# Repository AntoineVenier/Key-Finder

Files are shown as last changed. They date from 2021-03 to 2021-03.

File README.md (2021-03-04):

# Key Tracker

The goal of this project is to design a small embedded device that you can attach to your key in order to find them when they are lost.

## How it work

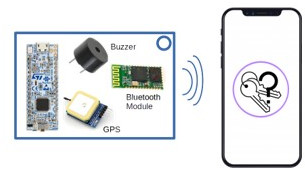
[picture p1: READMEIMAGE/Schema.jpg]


On the board which is attach to your key you have nucleo board which communicate with a GPS and Send the Location of the key to a mobile application thanks to a Bluetooth Module.
You can also detect the location of the key by making sound the buzzer.

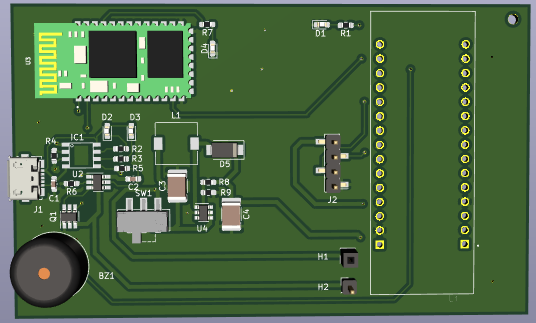
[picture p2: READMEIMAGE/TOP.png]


                                    TOP

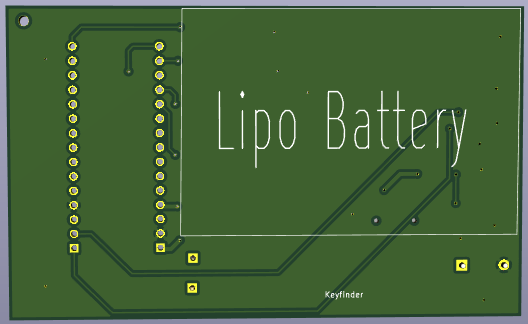
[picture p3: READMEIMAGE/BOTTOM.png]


                                     BOTTOM

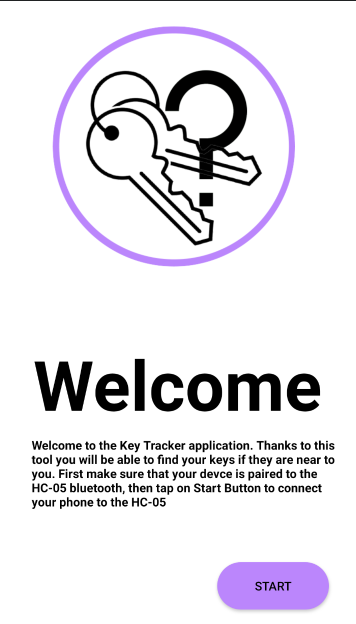
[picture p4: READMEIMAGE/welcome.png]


            Application Welcome page

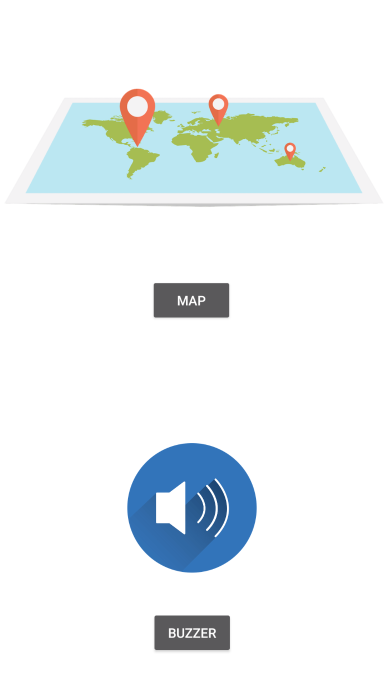
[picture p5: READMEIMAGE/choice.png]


            Application choice page

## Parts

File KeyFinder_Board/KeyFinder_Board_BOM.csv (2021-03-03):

Comment | Designator | Footprint | LCSC Part Numbers
10µF | C1 | Capacitor_SMD:C_0603_1608Metric_Pad1.08x0.95mm_HandSolder | C19702
0.1µF | C2 | Capacitor_SMD:C_0603_1608Metric_Pad1.08x0.95mm_HandSolder | C14663
22µF | C3,C4 | Capacitor_SMD:C_1812_4532Metric_Pad1.57x3.40mm_HandSolder | C59461
LED-RED | D2 | LED_SMD:LED_0603_1608Metric_Pad1.05x0.95mm_HandSolder | C2286
LED-GREEN | D1,D3 | LED_SMD:LED_0603_1608Metric_Pad1.05x0.95mm_HandSolder | C72043
LED-BLUE | D4 | LED_SMD:LED_0603_1608Metric_Pad1.05x0.95mm_HandSolder | C72041
SS34 | D5 | Diode_SMD:D_SMA | C8678
TP4056 | IC1 | mes_empreintes:SOP-8 | C16581
USB_B_Micro | J1 | Connector_USB:USB_Micro-B_Molex_47346-0001 | C404969
22µH | L1 | Inductor_SMD:L_7.3x7.3_H4.5 | C237916
FS8205 | Q1 | mes_empreintes:FS312F-G_SOT-23-6 | C32254
120 | R1 | Resistor_SMD:R_0603_1608Metric_Pad0.98x0.95mm_HandSolder | C22787
1K | R2,R3,R9 | Resistor_SMD:R_0603_1608Metric_Pad0.98x0.95mm_HandSolder | C21190
2K | R4,R6 | Resistor_SMD:R_0603_1608Metric_Pad0.98x0.95mm_HandSolder | C22975
100 | R5 | Resistor_SMD:R_0603_1608Metric_Pad0.98x0.95mm_HandSolder | C22775
47 | R7 | Resistor_SMD:R_0603_1608Metric_Pad0.98x0.95mm_HandSolder | C23182
7,5K | R8 | Resistor_SMD:R_0603_1608Metric_Pad0.98x0.95mm_HandSolder | C23234
SW_SPDT | SW1 | Button_Switch_SMD:SW_SPDT_CK-JS102011SAQN | C405951
FS312F-G | U2 | mes_empreintes:FS312F-G_SOT-23-6 | C82736
MT3608 | U4 | Package_TO_SOT_SMD:SOT-23-6 | C84817

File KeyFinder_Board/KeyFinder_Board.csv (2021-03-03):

Comment | Designator | Footprint | LCSC Part Number
Buzzer | BZ1 | Buzzer_Beeper:Buzzer_12x9.5RM7.6
10µF | C1 | Capacitor_SMD:C_0603_1608Metric_Pad1.08x0.95mm_HandSolder | C19702
0.1µF | C2 | Capacitor_SMD:C_0603_1608Metric_Pad1.08x0.95mm_HandSolder | C14663
22µF | C3,C4 | Capacitor_SMD:C_1812_4532Metric_Pad1.57x3.40mm_HandSolder | C59461
LED-RED | D2 | LED_SMD:LED_0603_1608Metric_Pad1.05x0.95mm_HandSolder | C2286
LED-GREEN | D1,D3 | LED_SMD:LED_0603_1608Metric_Pad1.05x0.95mm_HandSolder | C72043
LED-BLUE | D4 | LED_SMD:LED_0603_1608Metric_Pad1.05x0.95mm_HandSolder | C72041
SS34 | D5 | Diode_SMD:D_SMA | C8678
BAT+ | H1 | Connector_PinSocket_2.54mm:PinSocket_1x01_P2.54mm_Vertical
BAT- | H2 | Connector_PinHeader_2.54mm:PinHeader_1x01_P2.54mm_Vertical
TP4056 | IC1 | mes_empreintes:SOP-8 | C16581
USB_B_Micro | J1 | Connector_USB:USB_Micro-B_Molex_47346-0001 | C404969
GPS-NEO | J2 | Connector_PinHeader_2.54mm:PinHeader_1x04_P2.54mm_Vertical_SMD_Pin1Left
22µH | L1 | Inductor_SMD:L_7.3x7.3_H4.5 | C207843
FS8205 | Q1 | Package_TO_SOT_SMD:SOT-23-6_Handsoldering | C32254
120 | R1 | Resistor_SMD:R_0603_1608Metric_Pad0.98x0.95mm_HandSolder | C22787
1K | R2,R3,R9 | Resistor_SMD:R_0603_1608Metric_Pad0.98x0.95mm_HandSolder | C21190
2K | R4,R6 | Resistor_SMD:R_0603_1608Metric_Pad0.98x0.95mm_HandSolder | C22975
100 | R5 | Resistor_SMD:R_0603_1608Metric_Pad0.98x0.95mm_HandSolder | C22775
47 | R7 | Resistor_SMD:R_0603_1608Metric_Pad0.98x0.95mm_HandSolder | C23182
7,5K | R8 | Resistor_SMD:R_0603_1608Metric_Pad0.98x0.95mm_HandSolder | C23234
SW_SPDT | SW1 | Button_Switch_SMD:SW_SPDT_CK-JS102011SAQN | C405951
NucleoBoard | U1 | mes_empreintes:MODULE_NUCLEO-L432KC
FS312F-G | U2 | Package_TO_SOT_SMD:SOT-23-6_Handsoldering | C82736
HC-05 | U3 | HC-05(1):XCVR_HC-05
MT3608 | U4 | Package_TO_SOT_SMD:SOT-23-6 | C84817

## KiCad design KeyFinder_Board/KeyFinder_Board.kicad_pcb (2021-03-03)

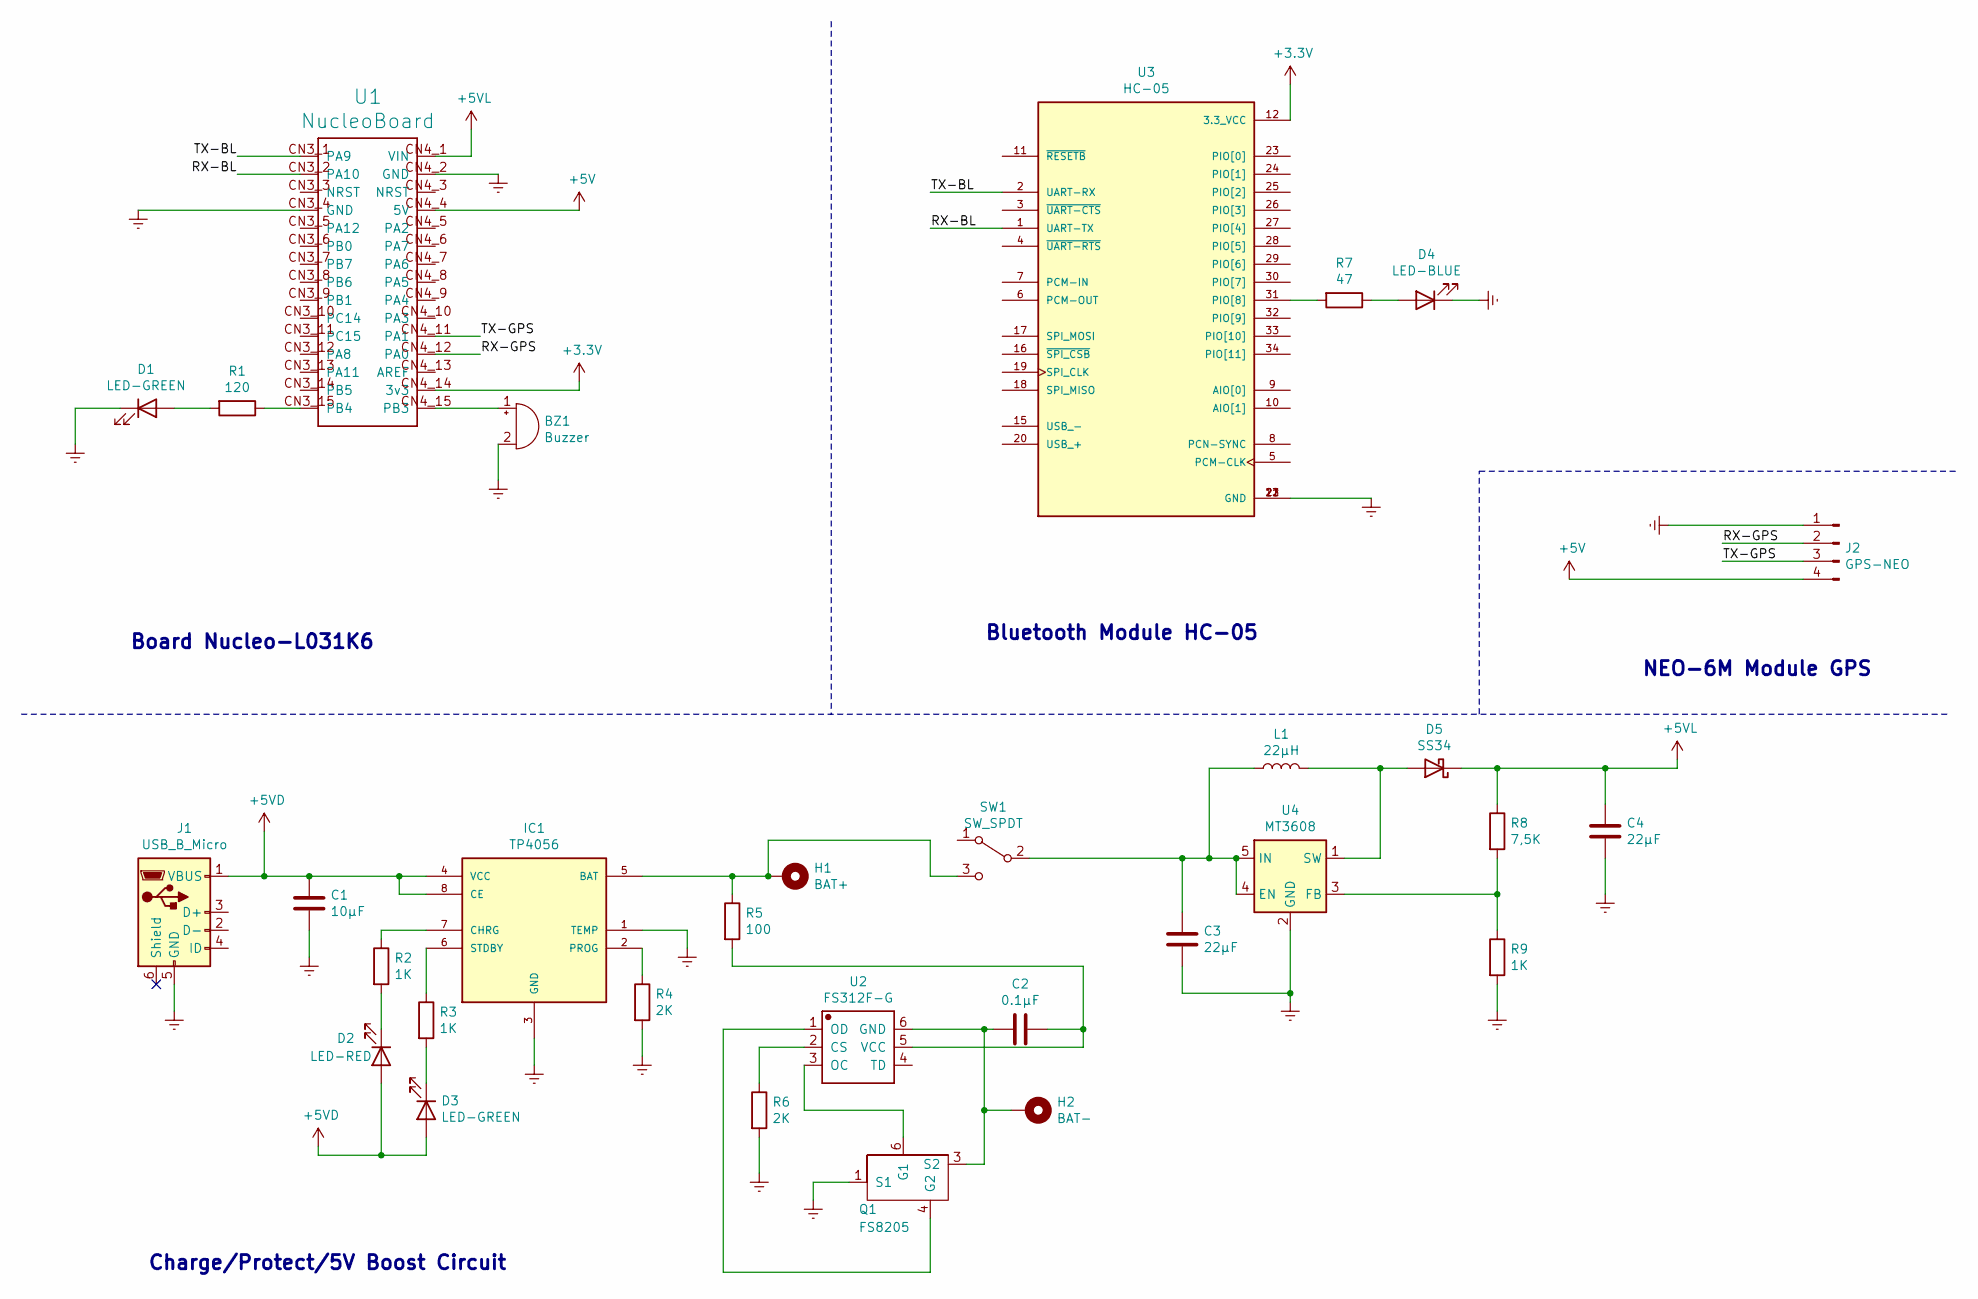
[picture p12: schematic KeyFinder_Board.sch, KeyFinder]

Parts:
BZ1: Buzzer; Buzzer_12x9.5RM7.6
C1: 10µF; C_0603_1608Metric_Pad1.08x0.95mm_HandSolder; LCSC C19702
C2: 0.1µF; C_0603_1608Metric_Pad1.08x0.95mm_HandSolder; LCSC C14663
C3, C4: 22µF; C_1812_4532Metric_Pad1.57x3.40mm_HandSolder; LCSC C59461
D1, D3: LED-GREEN; LED_0603_1608Metric_Pad1.05x0.95mm_HandSolder; LCSC C72043
D2: LED-RED; LED_0603_1608Metric_Pad1.05x0.95mm_HandSolder; LCSC C2286
D4: LED-BLUE; LED_0603_1608Metric_Pad1.05x0.95mm_HandSolder; LCSC C72041
D5: SS34; D_SMA; LCSC C8678
H1: BAT+; PinSocket_1x01_P2.54mm_Vertical
H2: BAT-; PinHeader_1x01_P2.54mm_Vertical
IC1: TP4056; SOP-8; LCSC C16581
J1: USB_B_Micro; USB_Micro-B_Molex_47346-0001; LCSC C404969
J2: GPS-NEO; PinHeader_1x04_P2.54mm_Vertical_SMD_Pin1Left
L1: 22µH; L_7.3x7.3_H4.5; LCSC C207843
Q1: FS8205; SOT-23-6_Handsoldering; LCSC C32254
R1: 120; R_0603_1608Metric_Pad0.98x0.95mm_HandSolder; LCSC C22787
R2, R3, R9: 1K; R_0603_1608Metric_Pad0.98x0.95mm_HandSolder; LCSC C21190
R4, R6: 2K; R_0603_1608Metric_Pad0.98x0.95mm_HandSolder; LCSC C22975
R5: 100; R_0603_1608Metric_Pad0.98x0.95mm_HandSolder; LCSC C22775
R7: 47; R_0603_1608Metric_Pad0.98x0.95mm_HandSolder; LCSC C23182
R8: 7,5K; R_0603_1608Metric_Pad0.98x0.95mm_HandSolder; LCSC C23234
SW1: SW_SPDT; SW_SPDT_CK-JS102011SAQN; LCSC C405951
U1: NucleoBoard; MODULE_NUCLEO-L432KC
U2: FS312F-G; SOT-23-6_Handsoldering; LCSC C82736
U3: HC-05; XCVR_HC-05; PARTREV v1.0
U4: MT3608; SOT-23-6; LCSC C84817

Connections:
+3V3: U1.CN4_14 (3v3), U3.12 (3.3_VCC)
+5V: J2.4, U1.CN4_4 (5V)
+5VD: C1.1, D2.2 (A), D3.2 (A), IC1.4 (VCC), IC1.8 (CE), J1.1 (VBUS)
+5VL: C4.1, D5.1 (K), R8.1, U1.CN4_1 (VIN)
/RX-BL: U1.CN3_2 (PA10), U3.1 (UART-TX)
/RX-GPS: J2.2, U1.CN4_12 (PA0)
/TX-BL: U1.CN3_1 (PA9), U3.2 (UART-RX)
/TX-GPS: J2.3, U1.CN4_11 (PA1)
GNDREF: BZ1.2 (+), C1.2, C3.2, C4.2, D1.1 (K), D4.1 (K), IC1.1 (TEMP), IC1.3 (GND), J1.5 (GND), J2.1, Q1.1 (S1), R4.2, R6.2, R9.2, U1.CN3_4 (GND), U1.CN4_2 (GND), U3.13 (GND), U3.21 (GND), U3.22 (GND), U4.2 (GND)
unnamed: BZ1.1 (-), U1.CN4_15 (PB3)
unnamed: C2.1, R5.2, U2.5 (VCC)
unnamed: C2.2, H2.1, Q1.3 (S2), U2.6 (GND)
unnamed: C3.1, L1.1, SW1.2 (B), U4.4 (EN), U4.5 (IN)
unnamed: D1.2 (A), R1.2
unnamed: D2.1 (K), R2.2
unnamed: D3.1 (K), R3.2
unnamed: D4.2 (A), R7.1
unnamed: D5.2 (A), L1.2, U4.1 (SW)
unnamed: H1.1, IC1.5 (BAT), R5.1, SW1.3 (C)
unnamed: IC1.2 (PROG), R4.1
unnamed: IC1.6 (STDBY), R3.1
unnamed: IC1.7 (CHRG), R2.1
unnamed: Q1.4 (G2), U2.1 (OD)
unnamed: Q1.6 (G1), U2.3 (OC)
unnamed: R1.1, U1.CN3_15 (PB4)
unnamed: R6.1, U2.2 (CS)
unnamed: R7.2, U3.31 (PIO[8])
unnamed: R8.2, R9.1, U4.3 (FB)

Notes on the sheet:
Charge/Protect/5V Boost Circuit
NEO-6M Module GPS
Board Nucleo-L031K6
Bluetooth Module HC-05

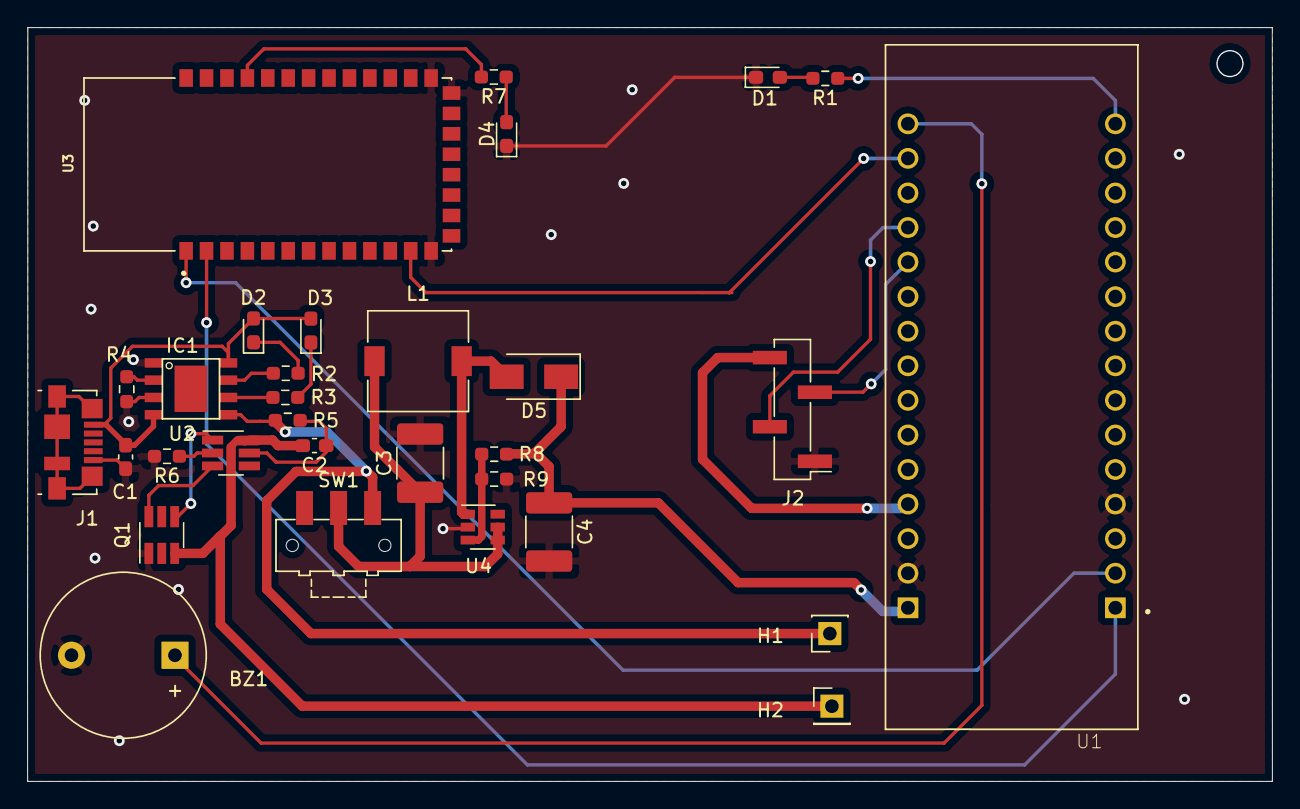
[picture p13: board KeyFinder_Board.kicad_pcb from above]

Board: 2 copper layers, 91.5 x 55.4 mm, 31 parts (0 on the bottom side), 28 nets.
